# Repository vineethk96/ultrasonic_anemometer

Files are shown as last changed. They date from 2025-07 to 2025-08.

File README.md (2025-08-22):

# Ultrasonic Anemometer Project

A complete 2D ultrasonic wind speed and direction measurement system with wireless data transmission and statistical analysis capabilities.

## Project Overview

This project implements a sonic anemometer that measures wind speed and direction using ultrasonic transducers. The system consists of three main components:

1. **Anemometer Device** - Arduino-based sensor that calculates wind measurements.
2. **WiFi Module** - ESP32-based wireless transmission system.
3. **Data Collection & Analysis** - Python scripts for data gathering and statistical analysis.
4. **CAD** - CAD Files for initial designs for 3D anemometer, and completed 2D anemometer. Along with the designs and laser-cut drawings for the model.

## System Architecture

```
[Ultrasonic Signal Board] → [Arduino Uno] → [Serial] → [ESP32] → [MQTT] → [Python Data Collector]
                                    ↓
                            [7-Segment Display]
```

## Hardware Requirements

### Anemometer Components
- Arduino Uno
- 3x Ultrasonic RX transducers (North, East, West)
- 1x Ultrasonic TX transducer
- 4-digit 7-segment display (common cathode)
- Various electronic components
- PCB

### WiFi Module Components
- ESP32 development board (ESP32-S3-DevKitC-1)
- Serial connection to anemometer Arduino

### Additional Components
- 9V Wall Wart with power pigtails
- Enclosure/mounting hardware (see CAD folder)

## Software Requirements

- **PlatformIO** (recommended) or Arduino IDE
- **Python 3.7+** with packages:
  - `paho-mqtt`
  - `pandas`
  - `numpy`
  - `statsmodels`
  - `scipy`

## Quick Start Guide

### 1. Hardware Setup
**_NOTE:_**  Please see [Instructable](https://www.instructables.com/Sonic-Anemometer/) for help in assembly. 
1. Build the anemometer circuit following the pin configurations in `anemometer/src/main.cpp`
2. Connect ultrasonic transducers
3. Wire the 7-segment display to digital pins 2-13
4. Connect Arduino to ESP32 via serial (9600 baud)

### 2. Software Installation
1. Install PlatformIO in VS Code
2. Clone this repository
3. Install Python dependencies:
   ```bash
   pip install paho-mqtt pandas numpy statsmodels scipy
   ```

### 3. Configuration
1. Create `arduino_secrets.h` in `WiFi_Module/include/` with your credentials:
   ```cpp
   #define SECRET_SSID "your_wifi_ssid"
   #define SECRET_PASS "your_wifi_password"
   #define SECRET_MQTTUSER "your_mqtt_username"
   #define SECRET_MQTTPASS "your_mqtt_password"
   ```

### 4. Upload Code
1. Upload `anemometer` code to Arduino Micro/Uno
2. Upload `WiFi_Module` code to ESP32

### 5. Data Collection
1. Run the MQTT collector:
   ```bash
   cd data_collector
   python mqtt_collector.py
   ```
2. Follow prompts to collect 200 readings
3. Use `merger.py` to combine multiple CSV files
4. Run `analysis.py` for statistical analysis

## Calibration

The anemometer requires calibration in three conditions:
1. **Still air** (calm conditions)
2. **Known north wind** (9 m/s reference)
3. **Known east wind** (9 m/s reference)

Update the calibration values in `anemometer/src/main.cpp`:
```cpp
const Wind_t calm =   {547, 581}; // Still air readings
const Wind_t north =  {850, 226}; // North wind readings  
const Wind_t east =   {720, 712}; // East wind readings
```

## Data Format

The system outputs JSON-formatted wind data:
```json
{"speed": 5.50, "direction": 126}
```

Where:
- `speed`: Wind speed in m/s
- `direction`: Wind direction in degrees (0-360°, meteorological convention)

## Folder Structure

```
├── anemometer/          # Arduino code for wind calculations
│   ├── src/main.cpp     # Main anemometer logic
│   ├── lib/sevSeg/      # 7-segment display library
│   └── platformio.ini   # Build configuration
├── WiFi_Module/         # ESP32 WiFi transmission code
│   ├── src/main.cpp     # MQTT publishing logic
│   └── platformio.ini   # ESP32 build configuration
├── data_collector/      # Python data collection tools
│   ├── mqtt_collector.py   # MQTT data collection script
│   ├── merger.py           # CSV file merger utility
│   └── analysis.py         # Statistical analysis tools
└── CAD/                 # 3D models and mechanical designs
    ├── Device             # STL files to print 2D Anemometer
    └── Exhibit            # Mix of STL and DXF files to make scaled
```

## Detailed Documentation

Each folder contains its own README with specific setup instructions:
- [Anemometer README](anemometer/README.md) - Arduino setup and calibration
- [WiFi Module README](WiFi_Module/README.md) - ESP32 configuration and MQTT setup
- [Data Collector README](data_collector/README.md) - Python tools and analysis

## Troubleshooting

### Common Issues

**No MQTT data received:**
- Check WiFi credentials in `arduino_secrets.h`
- Verify MQTT broker connectivity
- Ensure serial connection between Arduino and ESP32

**Incorrect wind measurements:**
- Recalibrate sensors in known conditions
- Check transducer positioning (East/West alignment)
- Verify analog pin connections

**7-segment display not working:**
- Check pin connections match code configuration
- Verify common cathode display type
- Test with simple digit display first

## Contributing

1. Fork the repository
2. Create a feature branch
3. Make your changes
4. Test with hardware setup
5. Submit a pull request

## License

This project is open source. See individual files for specific licensing information.

## Acknowledgments

This project uses:
- PlatformIO for embedded development
- PubSubClient library for MQTT communication
- ArduinoJson for data formatting
- Python scientific stack for data analysis
- Claude Sonnet 4 was used in the following capacities on the Python scripts:
   - Merging CSV files
   - Cleaning up the output of scripts
   - Conducting ANOVA tests

---

For detailed component-specific instructions, see the README files in each subfolder.

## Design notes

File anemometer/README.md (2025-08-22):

# Anemometer - Wind Measurement Module

This folder contains the Arduino code for the ultrasonic anemometer that calculates 2D wind speed and direction measurements.

## Overview

The anemometer uses three ultrasonic transducers positioned North, East, and West to measure wind speed and direction through phase-shift calculations. Wind data is displayed on a 7-segment display and transmitted via serial to the WiFi module.

## Hardware Requirements

- **Arduino Uno**
- **3x RX Ultrasonic Transducers** (positioned North, East, West)
- **1x TX Ultrasonic Transducer** 
- **4-digit 7-segment display** (common cathode)
- **Resistors** (220Ω recommended for segment limiting)
- **Various other electrical components**

## Pin Configuration

### Analog Inputs
- `A0` - West ultrasonic transducer
- `A1` - East ultrasonic transducer
- North RX Transducer is phase-locked to TX

### 7-Segment Display (Common Cathode)
#### Digit Control Pins:
- `Pin 3` - Digit 1 (leftmost)
- `Pin 2` - Digit 2  
- `Pin 13` - Digit 3
- `Pin 12` - Digit 4 (rightmost)

#### Segment Control Pins (a, b, c, d, e, f, g, dp):
- `Pin 4` - Segment A
- `Pin 5` - Segment B
- `Pin 6` - Segment C
- `Pin 7` - Segment D
- `Pin 8` - Segment E
- `Pin 9` - Segment F
- `Pin 10` - Segment G
- `Pin 11` - Decimal Point

## Software Setup

### 1. Install PlatformIO
Install the PlatformIO extension in VS Code or use PlatformIO Core.

### 2. Open Project
Open the `anemometer` folder in PlatformIO.

### 3. Select Environment
The `platformio.ini` file defines two environments:
- `uno` - for Arduino Uno

Select the appropriate environment in PlatformIO.

### 4. Upload Code
```bash
pio run --target upload --environment uno
```

## Calibration Process

The anemometer requires calibration in three wind conditions. Update these values in `src/main.cpp`:

```cpp
// Calibration values for the sensors in still air
const Wind_t calm =   {547, 581}; // W, E sensor readings in calm air
const Wind_t north =  {850, 226}; // W, E sensor readings in 10 m/s north wind  
const Wind_t east =   {720, 712}; // W, E sensor readings in 10 m/s east wind
```

### Calibration Steps:
1. **Calm Air Calibration:**
   - Place anemometer in still air conditions
   - Record average readings from both sensors
   - Update `calm` values

2. **North Wind Calibration:**
   - Generate known 9 m/s wind from north direction
   - Record sensor readings
   - Update `north` values

3. **East Wind Calibration:**
   - Generate known 9 m/s wind from east direction
   - Record sensor readings  
   - Update `east` values

## Code Structure

### Main Components

#### `main.cpp`
- **Wind Calculation Algorithm:** Implements 2D vector wind speed/direction calculation
- **Moving Average Filter:** 50-sample rolling average for noise reduction
- **Sensor Reading:** Alternates between East/West sensors every 100μs
- **Display Control:** Updates 7-segment display every second
- **Serial Output:** Sends JSON wind data via serial

#### Custom Library: `sevSeg`
Located in `lib/sevSeg/`, this library handles the 4-digit 7-segment display:

- **`sevSeg.hpp`** - Class definition and interface
- **`sevSeg.cpp`** - Implementation with digit encoding and multiplexing

### Key Parameters

```cpp
#define ADC_DELAY_US 100          // Delay between sensor readings (μs)
#define MOVING_AVERAGE_SIZE 50    // Rolling average window size
#define DISPLAY_UPDATE_RATE 1000  // Display refresh rate (ms)
```

### Data Structures

```cpp
typedef struct{
  float windSpeed;     // Wind speed in m/s
  int windDirection;   // Wind direction in degrees (0-360°)
} WindData_t;

typedef struct{
  int W;  // West sensor reading
  int E;  // East sensor reading  
} Wind_t;
```

## Algorithm Details

### Wind Calculation Process
1. **Sensor Reading:** Alternates between East/West transducers
2. **Moving Average:** Maintains 50-sample rolling average for each sensor
3. **Vector Calculation:** 
   - Calculates North and East wind components using calibration data
   - Uses linear interpolation between calm and reference wind conditions
4. **Wind Speed:** `sqrt(north² + east²) / 2`
5. **Wind Direction:** `atan2(north, east)` converted to 0-360° meteorological convention

### Output Format
```json
{"speed":5.50,"direction":126}
```

Serial output at 9600 baud for transmission to WiFi module.

## Display Features

- **Wind Speed Display:** Shows current wind speed in m/s (integer value)
- **Multiplexed Display:** Efficient 4-digit display with 1ms refresh rate
- **Leading Zero Suppression:** Hides unnecessary leading zeros
- **Range:** Displays 0-9999 (wind speeds over 999 m/s show as 9999)

## Troubleshooting

### No Display Output
- Check 7-segment display wiring
- Verify common cathode display type
- Test individual segments with simple code

### Incorrect Wind Readings
- Recalibrate sensors with known wind conditions
- Check transducer alignment (ensure East-West positioning)
- Verify analog input connections

### Erratic Readings
- Increase moving average window size
- Check for electrical interference
- Ensure stable power supply

### Serial Communication Issues
- Verify 9600 baud rate setting
- Check serial connection to ESP32
- Monitor serial output with Arduino IDE Serial Monitor

## Monitoring and Testing

### Serial Monitor Output
Connect to the Arduino's serial port at 9600 baud to see:
- JSON wind data: `{"speed":X.XX,"direction":XXX}`
- Calibration verification data
- Error messages and diagnostics

### Testing Procedure
1. Upload code to Arduino
2. Open Serial Monitor (9600 baud)
3. Verify JSON output format
4. Test display with known wind conditions
5. Validate readings against reference measurements

## Performance Specifications

- **Update Rate:** Wind calculations every 200μs (5 kHz)
- **Display Update:** 1 Hz (1 second intervals)
- **Serial Output:** Continuous JSON stream
- **Accuracy:** Depends on calibration quality and sensor positioning
- **Range:** 0-999 m/s (display limitation)

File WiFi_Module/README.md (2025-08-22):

# WiFi Module - Wireless Data Transmission

This folder contains the ESP32 code for wireless transmission of wind data via MQTT protocol.

## Overview

The WiFi module receives JSON wind data from the anemometer via serial communication and publishes it to an MQTT broker for remote data collection and analysis.

## Hardware Requirements

- **ESP32 Development Board** (one of the following):
  - ESP32-S3-DevKitC-1 (recommended)
  - ESP32-DevKit-V4
- **Serial connection** to Arduino anemometer (3.3V/5V compatible)
- **USB cable** for programming and power
- **WiFi network** access

## Pin Connections

### Serial Communication with Anemometer
- **RX Pin** - Connect to Arduino TX (Serial output from anemometer)
- **GND** - Common ground between ESP32 and Arduino
- **Power** - Ensure compatible voltage levels (3.3V/5V)

**Note:** ESP32 serial pins are typically GPIO1 (TX) and GPIO3 (RX) for Serial0, but this varies by board model.

## Software Setup

### 1. Install PlatformIO
Install PlatformIO extension in VS Code or use PlatformIO Core CLI.

### 2. Create Secrets File
Create `include/arduino_secrets.h` with your network credentials:

```cpp
#ifndef ARDUINO_SECRETS_H
#define ARDUINO_SECRETS_H

// WiFi Credentials
#define SECRET_SSID "your_wifi_network_name"
#define SECRET_PASS "your_wifi_password"

// MQTT Credentials  
#define SECRET_MQTTUSER "your_mqtt_username"
#define SECRET_MQTTPASS "your_mqtt_password"

#endif
```

**Security Note:** This file is in `.gitignore` to prevent credential exposure.

### 3. Select Board Environment
The `platformio.ini` defines two environments:

```ini
[env:esp32-s3-devkitc-1]    # For ESP32-S3 boards
[env:esp32-devkitC_v4]      # For ESP32 DevKit V4 boards
```

### 4. Upload Code
```bash
# For ESP32-S3
pio run --target upload --environment esp32-s3-devkitc-1

# For ESP32 DevKit V4  
pio run --target upload --environment esp32-devkitC_v4
```

## MQTT Configuration

### Broker Settings
The code is pre-configured for the CETools MQTT broker:
- **Host:** `mqtt.cetools.org`
- **Port:** `1884`
- **Topic:** `student/ultrasonic_anemometer`

### Topic Structure
Data is published to: `student/ultrasonic_anemometer`

### Authentication
Uses username/password authentication as defined in `arduino_secrets.h`.

## Code Structure

### Main Components

#### `main.cpp`
- **WiFi Management:** Automatic connection and reconnection
- **MQTT Client:** Handles broker connection and publishing
- **Serial Communication:** Receives data from anemometer at 9600 baud
- **Data Forwarding:** Publishes received JSON data to MQTT

### Key Functions

#### `startWifi()`
- Initializes WiFi connection
- Displays connection status and IP address
- Blocks until connected

#### `checkWifi()`
- Monitors WiFi connection status
- Automatically reconnects if disconnected
- Called every 10 seconds (INTERVAL)

#### `checkMQTT()`
- Maintains MQTT broker connection
- Handles authentication and reconnection
- Called continuously in main loop

#### `sendMQTT(char *msg)`
- Publishes wind data to MQTT topic
- Provides confirmation feedback via Serial
- Handles publish failures gracefully

### Connection Management
The system implements robust connection handling:
- **WiFi Auto-Reconnect:** Checks connection every 10 seconds
- **MQTT Persistence:** Maintains broker connection continuously
- **Error Recovery:** Automatic retry with delays
- **Status Reporting:** Serial output for debugging

## Data Flow

```
[Arduino] --Serial 9600--> [ESP32] --WiFi--> [MQTT Broker] ---> [Data Collector]
```

1. **Serial Input:** ESP32 receives JSON strings from Arduino
2. **Format Validation:** Accepts complete lines ending with `\n`
3. **MQTT Publishing:** Forwards data to configured topic
4. **Confirmation:** Serial feedback confirms successful transmission

## Expected Data Format

The system expects JSON wind data from the anemometer:
```json
{"speed":5.50,"direction":126}
```

Invalid formats are discarded with error messages.

## Monitoring and Debugging

### Serial Monitor Output
Connect to ESP32 at 9600 baud to monitor:
```
ESP32 MQTT
Connecting to WiFi..
Connected: 192.168.1.100
Attempting MQTT connection...connected
SENDING MSG...
Topic: student/ultrasonic_anemometer  
Message: {"speed":5.50,"direction":126}
Message published
```

### Connection Status Messages
- **WiFi:** IP address displayed on successful connection
- **MQTT:** Connection confirmation with client ID
- **Publish:** Topic and message content logged
- **Errors:** Failed connections and retry attempts

## Troubleshooting

### WiFi Connection Issues
1. **Check Credentials:**
   - Verify SSID and password in `arduino_secrets.h`
   - Ensure network is 2.4GHz (ESP32 limitation)

2. **Network Compatibility:**
   - Test with mobile hotspot
   - Check for enterprise/captive portal networks

3. **Signal Strength:**
   - Move closer to WiFi router
   - Check antenna connection on ESP32

### MQTT Connection Problems
1. **Broker Access:**
   - Verify `mqtt.cetools.org` is accessible
   - Test with MQTT client tools (mosquitto_pub/sub)

2. **Credentials:**
   - Confirm MQTT username/password
   - Check account permissions

3. **Firewall Issues:**
   - Ensure port 1884 is not blocked
   - Test from different network

### Serial Communication Issues
1. **Arduino Connection:**
   - Check serial wiring between Arduino and ESP32
   - Verify ground connection
   - Confirm voltage compatibility (3.3V/5V)

2. **Baud Rate:**
   - Both devices must use 9600 baud
   - Check Arduino serial output first

3. **Data Format:**
   - ESP32 expects complete lines (ending with `\n`)
   - Arduino should use `Serial.println()`

### No Data Publishing
1. **Check Serial Input:**
   - Monitor ESP32 serial for incoming messages
   - Verify Arduino is sending data

2. **MQTT Connection:**
   - Ensure MQTT client shows "connected" status
   - Test topic subscription with external client

3. **Message Format:**
   - ESP32 forwards received messages directly
   - Any string from Arduino will be published

## Performance Specifications

- **Serial Baud Rate:** 9600 bps
- **WiFi Standard:** 802.11 b/g/n (2.4GHz)
- **MQTT QoS:** 0 (fire-and-forget)
- **Reconnection Interval:** 10 seconds (WiFi), 5 seconds (MQTT)
- **Message Rate:** Unlimited (forwards all received data)

## Power Considerations

- **USB Power:** Suitable for development and testing
- **External Power:** 3.3V-5V DC input for permanent installation
- **Power Consumption:** ~160mA active, ~10μA deep sleep (if implemented)

## Libraries Used

- **WiFi:** ESP32 built-in WiFi library
- **PubSubClient:** MQTT client implementation (v2.8+)
- **ArduinoJson:** JSON formatting library (v7.4.2+)

These dependencies are automatically managed by PlatformIO.

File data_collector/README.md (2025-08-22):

# Data Collector - Python Analysis Tools

This folder contains Python scripts for collecting, processing, and analyzing wind data from the ultrasonic anemometer system.

## Overview

The data collector suite provides three main tools:
1. **MQTT Collector** - Real-time data collection from MQTT broker
2. **CSV Merger** - Combines multiple data files for analysis
3. **Statistical Analysis** - Comprehensive ANOVA and effect size analysis

## Requirements

### Python Version
- Python 3.7 or higher

### Required Packages
Create a Virtual Environment:
```bash
python -m venv analysis_env
```

Start Virtual Environment:
```bash
analysis_env\Scripts\activate
```

Install the required packages using pip:

```bash
pip install paho-mqtt pandas numpy statsmodels scipy
```

Or install from requirements file:
```bash
pip install -r requirements.txt
```

**_NOTE:_** Remember to deactivate Virtual Environment after use
```bash
deactivate
```

#### Package Details:
- `paho-mqtt>=1.6.1` - MQTT client for data collection
- `pandas>=1.3.0` - Data manipulation and analysis
- `numpy>=1.21.0` - Numerical computations
- `statsmodels>=0.12.0` - Statistical modeling and ANOVA
- `scipy>=1.7.0` - Scientific computing and statistics

## Tools Overview

### 1. MQTT Collector (`mqtt_collector.py`)

Connects to MQTT broker and collects 200 wind readings in real-time.

#### Usage:
```bash
python mqtt_collector.py
```

#### Interactive Setup:
1. **CSV Filename:** Enter desired output filename (`.csv` added automatically)
2. **MQTT Topic:** Enter the topic to subscribe to (e.g., `student/ultrasonic_anemometer`)
3. **Confirmation:** Review settings and confirm collection

#### Features:
- **Real-time Collection:** Streams live data from MQTT broker
- **Format Validation:** Parses JSON format `{"speed":X.XX,"direction":XXX}`
- **Progress Tracking:** Shows collection progress (X/200 readings)
- **Automatic Statistics:** Calculates mean, min, max, std deviation
- **Error Handling:** Graceful handling of connection issues
- **Interrupt Support:** Ctrl+C saves partial data

#### Output Format:
CSV file with columns:
- `timestamp` - ISO format timestamp
- `topic` - MQTT topic name
- `wind_speed` - Wind speed in m/s
- `wind_direction` - Wind direction in degrees

#### Example Output:
```csv
timestamp,topic,wind_speed,wind_direction
2024-01-15T14:30:15.123456,student/ultrasonic_anemometer,5.50,126
2024-01-15T14:30:16.234567,student/ultrasonic_anemometer,5.75,128
```

### 2. CSV Merger (`merger.py`)

Combines multiple CSV files into a single summary file for batch analysis.

#### Usage:
```bash
python merger.py
```

#### Interactive Process:
1. **Directory Path:** Enter path containing CSV files
2. **File Discovery:** Automatically finds all `.csv` files
3. **Processing:** Extracts wind_speed data from each file
4. **Output:** Creates `wind_speed_summary.csv`

#### Features:
- **Batch Processing:** Handles multiple CSV files automatically
- **Column Validation:** Verifies required columns exist
- **Filename Preservation:** Creates unique column names from filenames
- **Error Handling:** Skips invalid files with warnings
- **Data Preview:** Shows first few rows of combined data

#### Output Structure:
```csv
index,file1_wind_speed,file2_wind_speed,file3_wind_speed
1,5.50,6.20,4.80
2,5.75,6.45,4.95
```

### 3. Statistical Analysis (`analysis.py`)

Performs comprehensive statistical analysis on wind speed data collected under different experimental conditions.

#### Usage:
```bash
python analysis.py
```

#### Required Data Structure:
The script expects CSV files organized by experimental conditions in a `readings/` directory:

```
readings/
├── aboveTreeLevel/
│   ├── open.csv
│   ├── half_building.csv
│   ├── closed_park.csv
│   └── ...
├── treeLevel/
│   └── ...
└── groundLevel/
    └── ...
```

#### Experimental Factors:
- **Height:** `aboveTreeLevel`, `treeLevel`, `groundLevel`
- **Width:** `open`, `half`, `closed`  
- **Obstacles:** `none`, `building`, `park`

#### Statistical Methods:

##### 1. Two-Way ANOVA (by height level)
- **Factors:** Width × Obstacles
- **Response:** Wind speed
- **Type:** Type II ANOVA (balanced designs)

##### 2. Three-Way ANOVA (all data)
- **Factors:** Height × Width × Obstacles
- **Includes:** All main effects and interactions

##### 3. Effect Size Analysis
- **Omega Squared (ω²):** Less biased than eta squared
- **Interpretation:** 
  - < 0.01: negligible
  - 0.01-0.06: small
  - 0.06-0.14: medium  
  - ≥ 0.14: large

##### 4. Specific Contrasts
- **Obstacle Effects:** Building vs None, Park vs None
- **Confidence Intervals:** 95% CI for effect differences
- **Interaction Analysis:** Effects by height level

#### Output Features:
- **Data Quality Checks:** Sample sizes, missing data, descriptive stats
- **ANOVA Tables:** F-statistics, p-values, degrees of freedom
- **Effect Sizes:** Omega squared with magnitude interpretation
- **Contrast Analysis:** Specific comparisons of interest
- **Summary Statistics:** Overall dataset characteristics

#### Example Output:
```
TWO-WAY ANOVA ANALYSES BY HEIGHT
================================

Two-Way ANOVA for aboveTreeLevel
================================
                    sum_sq    df         F    PR(>F)
C(width)            45.23     2    8.756   0.0003
C(obstacles)        12.34     2    2.389   0.0956
C(width):C(obstacles) 3.45   4    0.334   0.8551
Residual           234.56    91

Omega Squared (O_sq) Effect Sizes:
-----------------------------------
C(width)                      : O_sq = 0.1234 (medium)
C(obstacles)                  : O_sq = 0.0234 (small)
C(width):C(obstacles)         : O_sq = 0.0000 (negligible)
```

## Workflow Example

### Complete Data Collection and Analysis Workflow:

1. **Collect Data:**
   ```bash
   python mqtt_collector.py
   # Collect data for each experimental condition
   # Example: open_none_height1.csv, open_building_height1.csv, etc.
   ```

2. **Organize Data:**
   ```
   mkdir -p readings/aboveTreeLevel readings/treeLevel readings/groundLevel
   # Move CSV files to appropriate directories
   # Rename files to match expected format (width_obstacle.csv)
   ```

3. **Optional - Merge Multiple Files:**
   ```bash
   python merger.py
   # If you have multiple files per condition to combine
   ```

4. **Run Analysis:**
   ```bash
   python analysis.py
   # Performs complete statistical analysis
   ```

## Data Quality Requirements

### File Naming Convention:
- Format: `{width}_{obstacle}.csv` (e.g., `open_building.csv`)
- Width options: `open`, `half`, `closed`
- Obstacle options: `none`, `building`, `park`
- Special case: Files with just width name (e.g., `open.csv`) assume `obstacle = none`

### CSV Structure:
Required columns in each CSV file:
- `wind_speed` - Numerical wind speed values
- Other columns (timestamp, topic, wind_direction) are preserved but not required for analysis

### Sample Size Considerations:
- **Minimum:** 30 readings per condition for reliable statistics
- **Recommended:** 200 readings per condition for robust analysis
- **Balance:** Equal sample sizes across conditions improve ANOVA reliability

## Troubleshooting

### MQTT Collection Issues:

**Connection Failed:**
```
Failed to connect to MQTT broker. Return code: X
```
- Check internet connection
- Verify MQTT broker address (`mqtt.cetools.org`)
- Test with MQTT client tools

**No Data Received:**
```
Skipped invalid format: some_message
```
- Check ESP32 is publishing to correct topic
- Verify data format: `{"speed":X.XX,"direction":XXX}`
- Monitor Arduino serial output

**Incomplete Collection:**
- Use Ctrl+C to save partial data
- Check WiFi stability during collection
- Restart collection if needed

### Analysis Issues:

**File Not Found:**
```
FileNotFoundError: readings/ directory not found
```
- Create `readings/` directory structure
- Move CSV files to appropriate subdirectories
- Check file naming convention

**Missing Columns:**
```
KeyError: 'wind_speed' column not found
```
- Verify CSV files have `wind_speed` column
- Check column names match exactly
- Review CSV file structure

**Insufficient Data:**
```
Warning: Small sample size in condition X
```
- Collect more data for affected conditions
- Consider combining similar conditions
- Check for missing experimental conditions

### CSV Merger Issues:

**No CSV Files Found:**
```
No CSV files found in directory 'path'
```
- Check directory path is correct
- Ensure files have `.csv` extension
- Verify file permissions

**Column Validation Failed:**
```
Warning: file.csv missing required columns. Skipping.
```
- Check CSV file structure
- Ensure required columns exist: `timestamp`, `topic`, `wind_speed`, `wind_direction`
- Review file formatting

## Performance Notes

- **MQTT Collection:** ~1-5 readings/second depending on transmission rate
- **CSV Merger:** Handles files up to 1M+ rows efficiently
- **Analysis:** Processing time scales with dataset size, typically <30 seconds for normal datasets

## Advanced Configuration

### MQTT Broker Settings:
Modify `mqtt_collector.py` to use different brokers:
```python
collector = MQTTDataCollector("your.mqtt.broker.com", port=1883)
```

### Analysis Customization:
Modify `analysis.py` for different experimental designs:
- Change factor names

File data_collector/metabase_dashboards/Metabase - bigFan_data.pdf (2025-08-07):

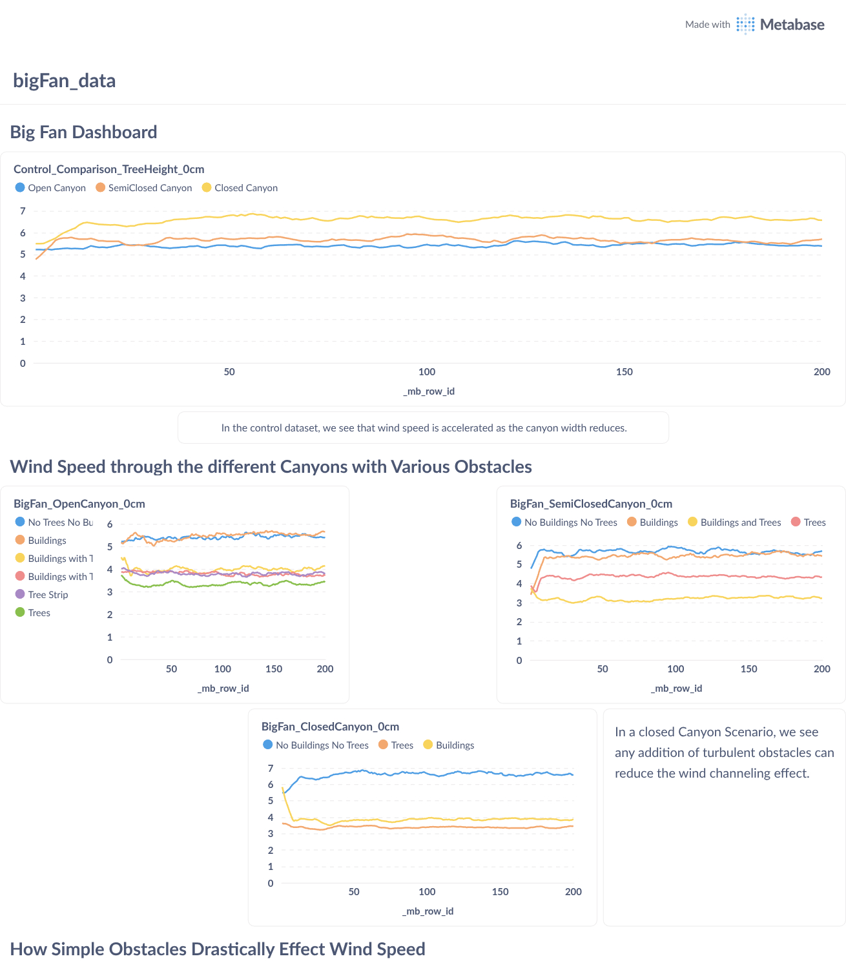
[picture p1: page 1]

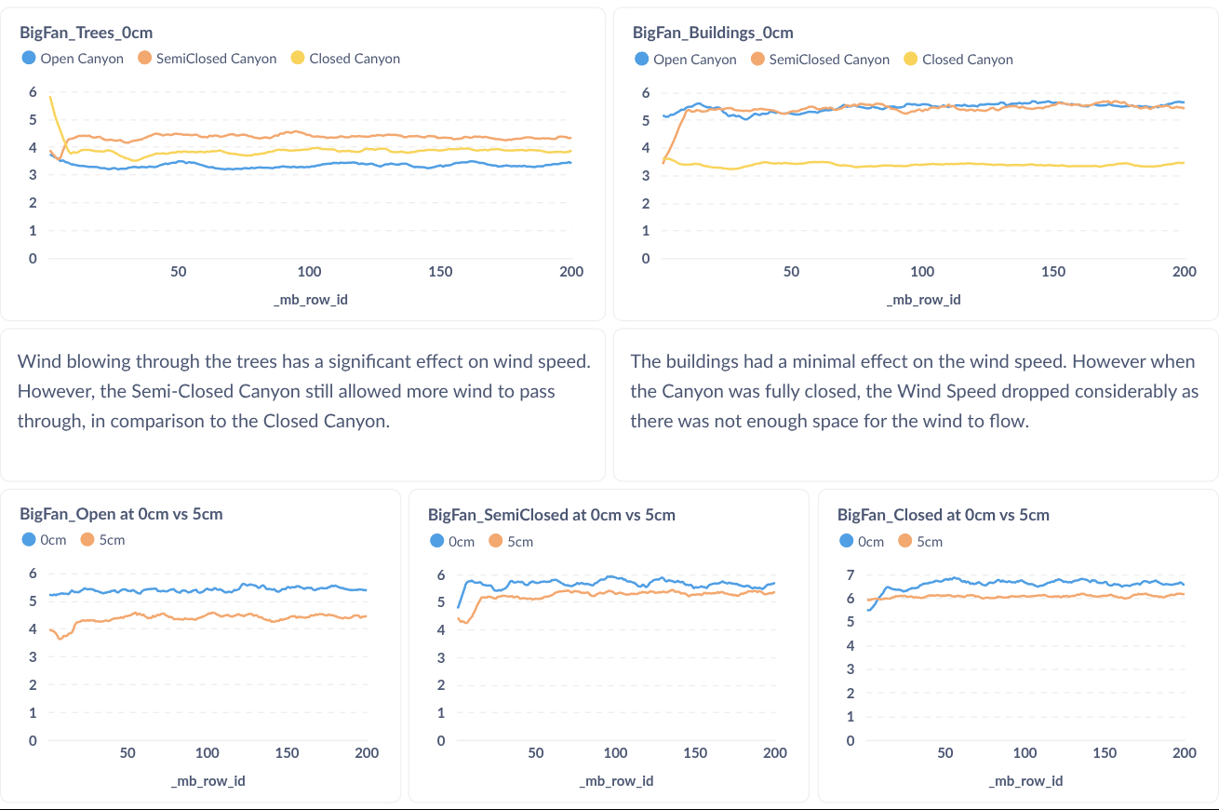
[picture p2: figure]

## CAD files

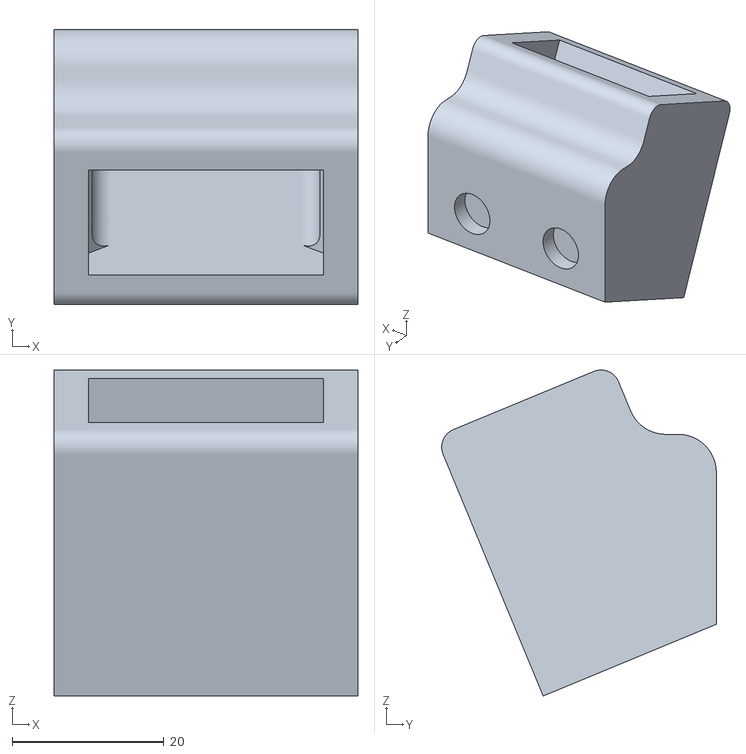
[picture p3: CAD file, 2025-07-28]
CAD/Device/screenHolder.stl
40.0 x 36.2 x 42.9

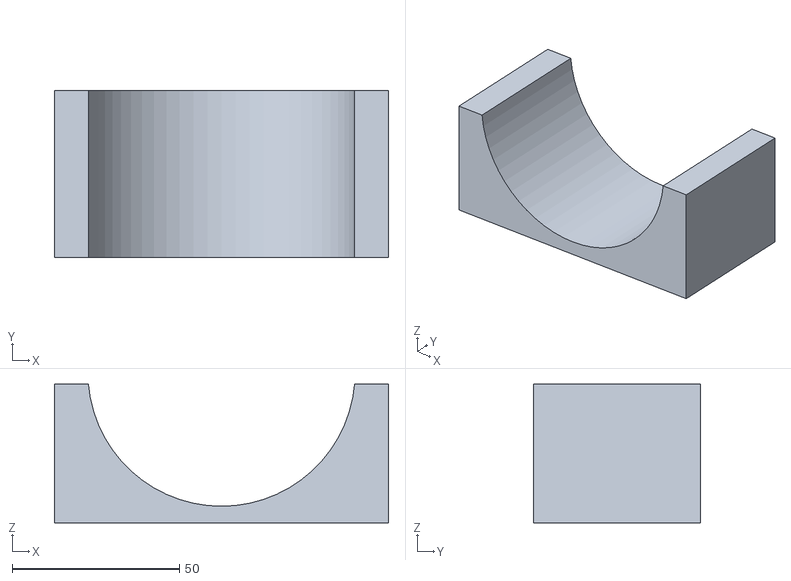
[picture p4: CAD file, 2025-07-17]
CAD/Exhibit/skateRamp - Part 1.stl
100.0 x 50.0 x 41.6

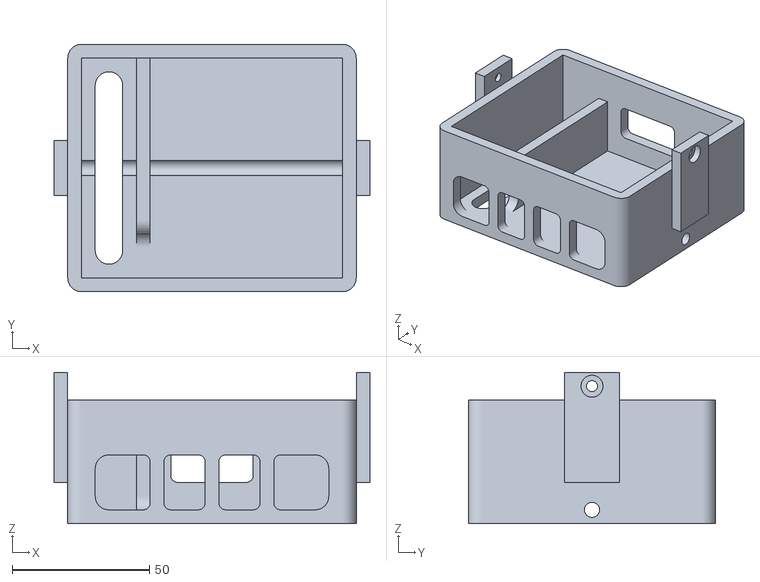
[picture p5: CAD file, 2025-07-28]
CAD/Device/arduinoBox.stl
115.0 x 90.0 x 55.0

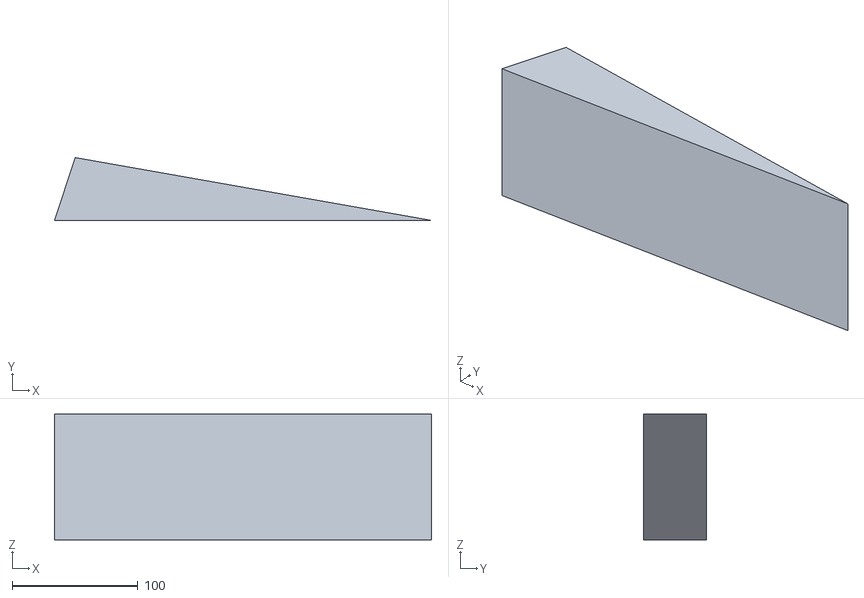
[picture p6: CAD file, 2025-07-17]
CAD/Exhibit/ramps - Part 1.stl
300.0 x 50.0 x 100.0

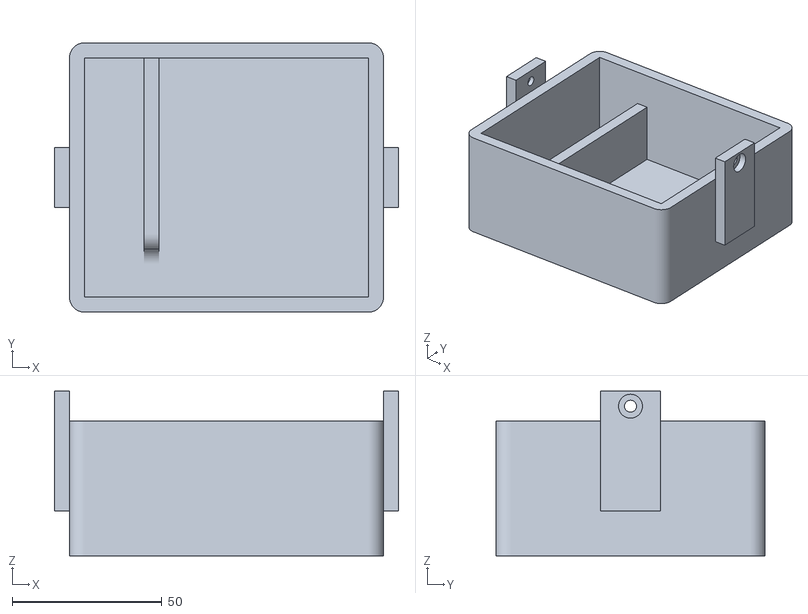
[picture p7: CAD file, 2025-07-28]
CAD/Device/batteryBox.stl
115.0 x 90.0 x 55.0

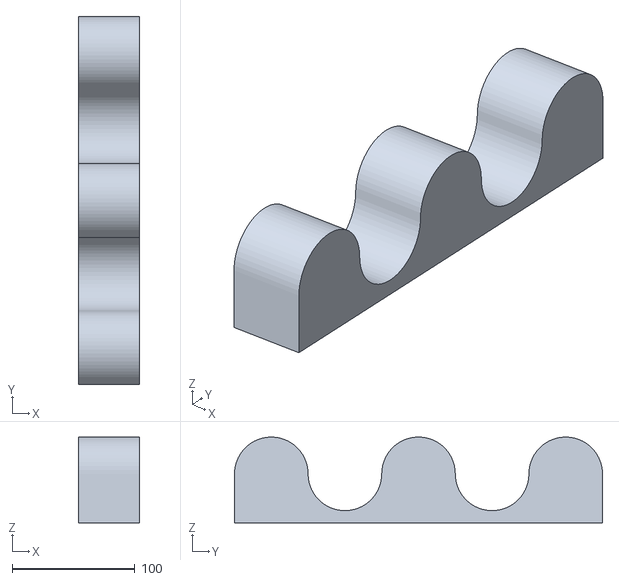
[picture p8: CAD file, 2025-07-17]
CAD/Exhibit/rollingHills - Part 1.stl
50.0 x 300.0 x 70.0

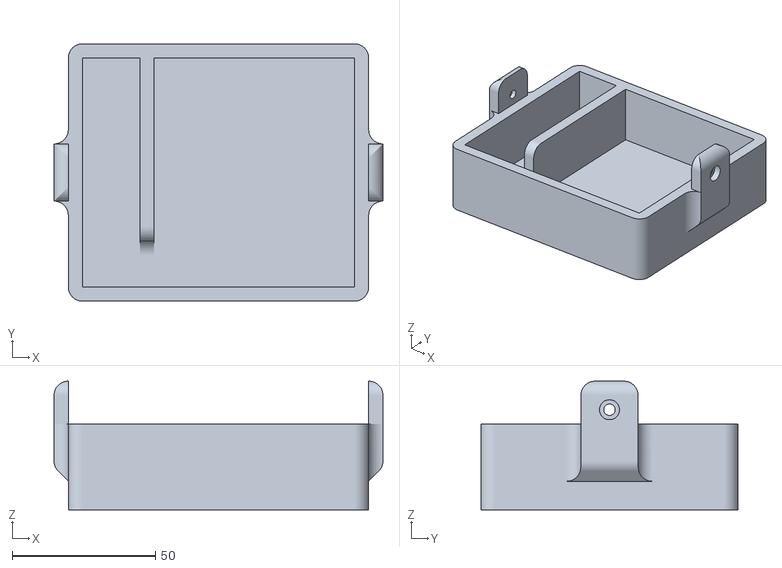
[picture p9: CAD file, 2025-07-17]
CAD/Device/circuitBox - Part 1.stl
115.0 x 90.0 x 45.0

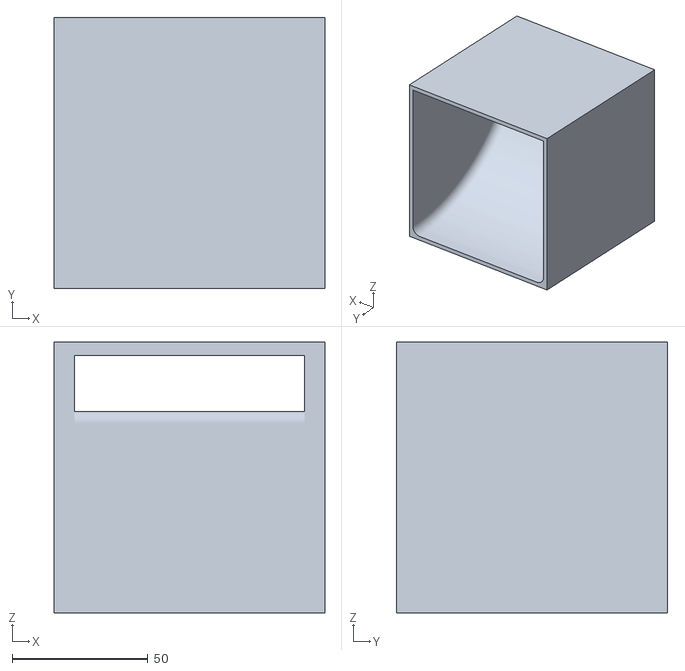
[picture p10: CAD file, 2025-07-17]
CAD/Exhibit/accelerator box - Part 1.stl
100.0 x 100.0 x 100.0

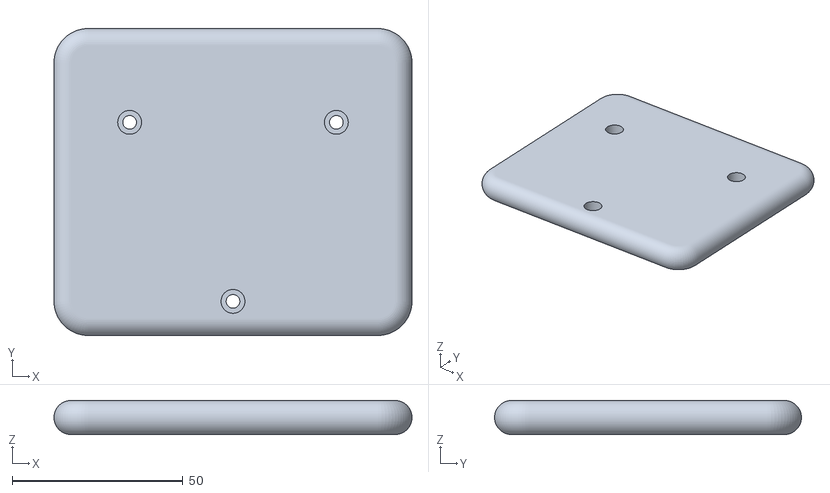
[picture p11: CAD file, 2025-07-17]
CAD/Device/reflector_plate- Part 1.stl
105.0 x 90.0 x 10.0

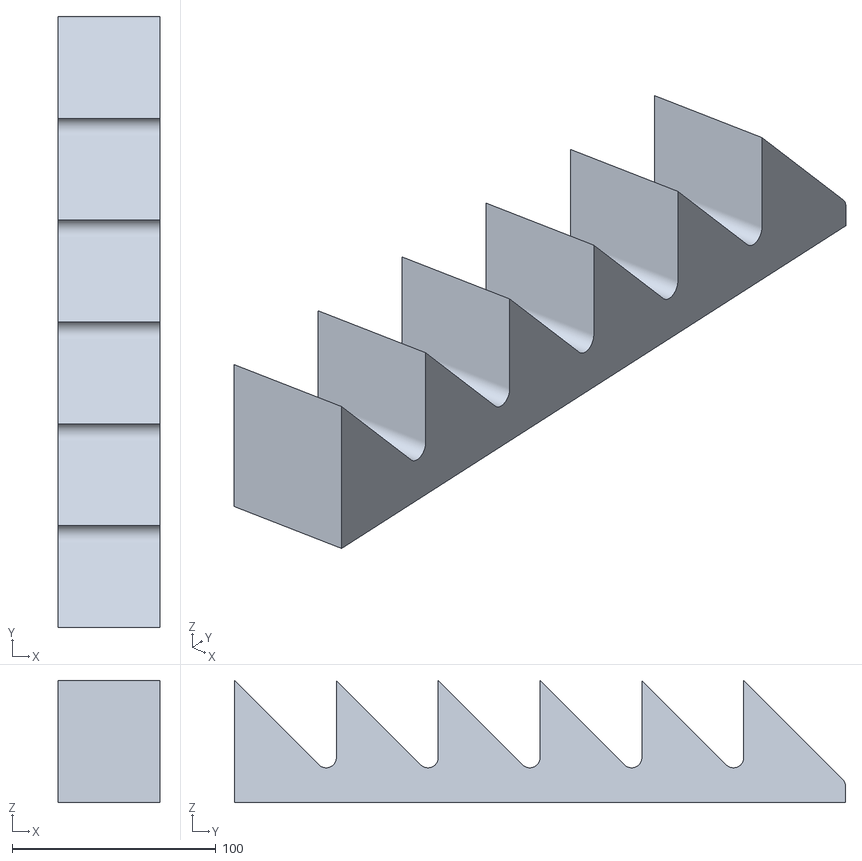
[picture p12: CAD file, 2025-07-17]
CAD/Exhibit/fins - Part 1.stl
50.0 x 300.0 x 60.0

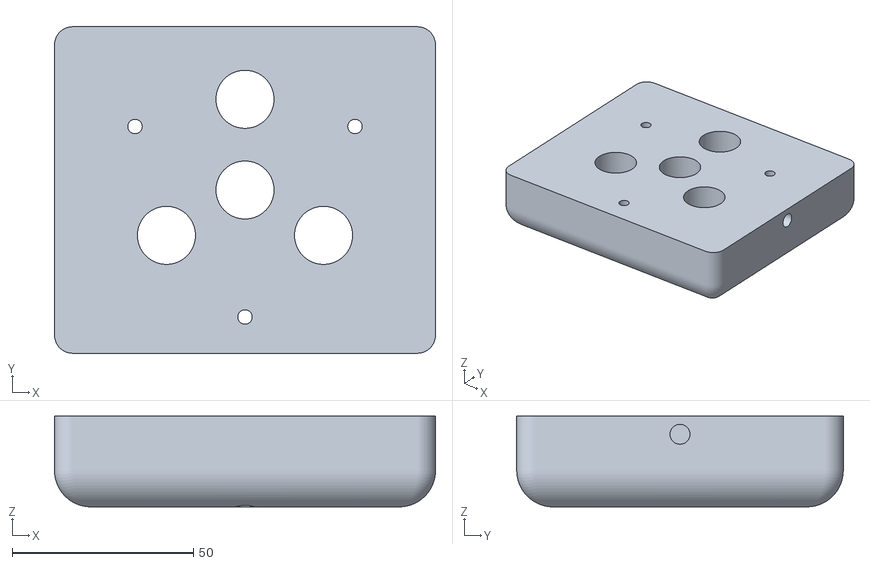
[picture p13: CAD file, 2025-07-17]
CAD/Device/rectangular_Tplate - Part 1.stl
105.0 x 90.0 x 25.0

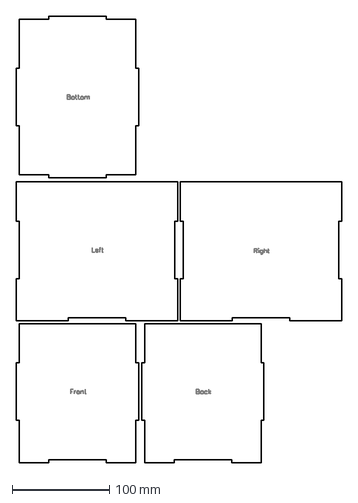
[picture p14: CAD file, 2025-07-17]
CAD/Exhibit/fanBox.dxf
335.0 x 459.5 mm

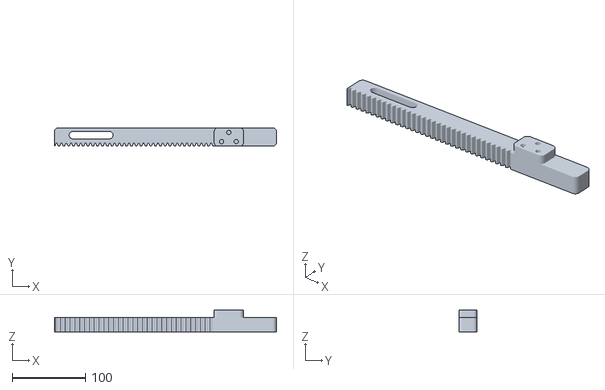
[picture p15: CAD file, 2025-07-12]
CAD/Exhibit/Upper Rack_v2.stl
303.0 x 25.0 x 30.0

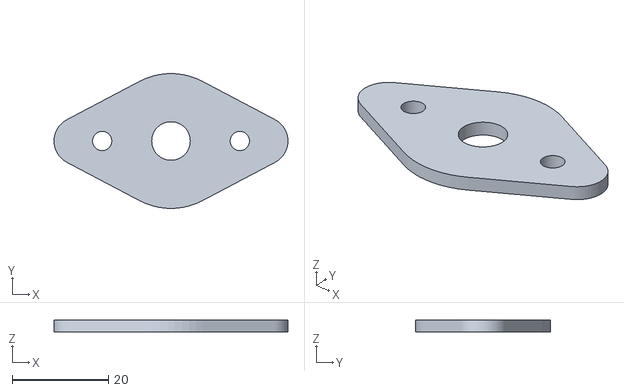
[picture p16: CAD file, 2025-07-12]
CAD/Exhibit/pinionGearMount.stl
48.6 x 28.0 x 2.40

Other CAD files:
CAD/Exhibit/baseBox.dxf
CAD/Exhibit/Spur Gear 36 Teeth - Spur Gear.stl
CAD/Exhibit/building.dxf
CAD/Exhibit/Upper Rack.stl
CAD/Exhibit/fins - Part 1.dxf
CAD/Exhibit/ramps - Part 1.dxf
CAD/Exhibit/rollingHills - Part 1.dxf
CAD/Exhibit/skateRamp - Part 1.dxf

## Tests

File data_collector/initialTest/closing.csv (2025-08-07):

timestamp | topic | wind_speed | wind_direction
2025-08-05T15:08:18.526827 | student/ultrasonic_anemometer | 5.45 | 126.0
2025-08-05T15:08:19.529580 | student/ultrasonic_anemometer | 5.4 | 126.0
2025-08-05T15:08:20.600967 | student/ultrasonic_anemometer | 5.41 | 126.0
2025-08-05T15:08:21.536490 | student/ultrasonic_anemometer | 5.42 | 127.0
2025-08-05T15:08:22.579929 | student/ultrasonic_anemometer | 5.4 | 126.0
2025-08-05T15:08:23.541967 | student/ultrasonic_anemometer | 5.43 | 127.0
2025-08-05T15:08:24.544860 | student/ultrasonic_anemometer | 5.42 | 127.0
2025-08-05T15:08:25.548267 | student/ultrasonic_anemometer | 5.51 | 127.0
2025-08-05T15:08:26.555499 | student/ultrasonic_anemometer | 5.5 | 127.0
2025-08-05T15:08:27.555338 | student/ultrasonic_anemometer | 5.52 | 127.0
2025-08-05T15:08:28.584310 | student/ultrasonic_anemometer | 5.47 | 127.0
2025-08-05T15:08:29.560540 | student/ultrasonic_anemometer | 5.45 | 126.0
2025-08-05T15:08:30.605926 | student/ultrasonic_anemometer | 5.41 | 127.0
2025-08-05T15:08:31.571754 | student/ultrasonic_anemometer | 5.38 | 127.0
2025-08-05T15:08:32.569605 | student/ultrasonic_anemometer | 5.38 | 127.0
2025-08-05T15:08:33.572508 | student/ultrasonic_anemometer | 5.39 | 127.0
2025-08-05T15:08:34.576635 | student/ultrasonic_anemometer | 5.39 | 127.0
2025-08-05T15:08:35.578340 | student/ultrasonic_anemometer | 5.34 | 127.0
2025-08-05T15:08:36.582919 | student/ultrasonic_anemometer | 5.29 | 126.0
2025-08-05T15:08:37.590792 | student/ultrasonic_anemometer | 5.27 | 127.0
2025-08-05T15:08:38.587421 | student/ultrasonic_anemometer | 5.31 | 127.0
2025-08-05T15:08:39.590636 | student/ultrasonic_anemometer | 5.37 | 127.0
2025-08-05T15:08:40.593125 | student/ultrasonic_anemometer | 5.46 | 127.0
2025-08-05T15:08:41.596597 | student/ultrasonic_anemometer | 5.45 | 127.0
2025-08-05T15:08:42.644411 | student/ultrasonic_anemometer | 5.42 | 127.0
2025-08-05T15:08:43.602490 | student/ultrasonic_anemometer | 5.42 | 126.0
2025-08-05T15:08:44.606381 | student/ultrasonic_anemometer | 5.4 | 126.0
2025-08-05T15:08:45.608591 | student/ultrasonic_anemometer | 5.36 | 125.0
2025-08-05T15:08:46.621764 | student/ultrasonic_anemometer | 5.41 | 126.0
2025-08-05T15:08:47.615998 | student/ultrasonic_anemometer | 5.4 | 125.0
2025-08-05T15:08:48.619613 | student/ultrasonic_anemometer | 5.4 | 126.0
2025-08-05T15:08:49.621772 | student/ultrasonic_anemometer | 5.42 | 126.0
2025-08-05T15:08:50.630488 | student/ultrasonic_anemometer | 5.35 | 126.0
2025-08-05T15:08:51.628371 | student/ultrasonic_anemometer | 5.36 | 126.0
2025-08-05T15:08:52.631207 | student/ultrasonic_anemometer | 5.39 | 127.0
2025-08-05T15:08:53.634158 | student/ultrasonic_anemometer | 5.35 | 127.0
2025-08-05T15:08:54.637040 | student/ultrasonic_anemometer | 5.36 | 127.0
2025-08-05T15:08:55.640112 | student/ultrasonic_anemometer | 5.44 | 128.0
2025-08-05T15:08:56.646258 | student/ultrasonic_anemometer | 5.42 | 128.0
2025-08-05T15:08:57.645799 | student/ultrasonic_anemometer | 5.4 | 128.0
2025-08-05T15:08:58.649128 | student/ultrasonic_anemometer | 5.46 | 128.0
2025-08-05T15:08:59.654860 | student/ultrasonic_anemometer | 5.46 | 128.0
2025-08-05T15:09:00.655539 | student/ultrasonic_anemometer | 5.41 | 127.0
2025-08-05T15:09:01.762784 | student/ultrasonic_anemometer | 5.37 | 128.0
2025-08-05T15:09:02.661400 | student/ultrasonic_anemometer | 5.28 | 128.0
2025-08-05T15:09:03.664324 | student/ultrasonic_anemometer | 5.27 | 128.0
2025-08-05T15:09:04.667983 | student/ultrasonic_anemometer | 5.21 | 128.0
2025-08-05T15:09:05.673141 | student/ultrasonic_anemometer | 5.17 | 127.0
2025-08-05T15:09:06.674169 | student/ultrasonic_anemometer | 5.18 | 126.0
2025-08-05T15:09:07.677027 | student/ultrasonic_anemometer | 5.25 | 126.0
2025-08-05T15:09:08.679238 | student/ultrasonic_anemometer | 5.19 | 124.0
2025-08-05T15:09:09.682429 | student/ultrasonic_anemometer | 5.19 | 124.0
2025-08-05T15:09:10.685374 | student/ultrasonic_anemometer | 5.26 | 123.0
2025-08-05T15:09:11.695530 | student/ultrasonic_anemometer | 5.42 | 123.0
2025-08-05T15:09:12.691995 | student/ultrasonic_anemometer | 5.53 | 121.0
2025-08-05T15:09:13.694426 | student/ultrasonic_anemometer | 5.6 | 121.0
2025-08-05T15:09:14.698119 | student/ultrasonic_anemometer | 5.72 | 122.0
2025-08-05T15:09:15.710940 | student/ultrasonic_anemometer | 5.82 | 123.0
2025-08-05T15:09:16.713632 | student/ultrasonic_anemometer | 5.83 | 122.0
2025-08-05T15:09:17.706515 | student/ultrasonic_anemometer | 5.83 | 122.0
2025-08-05T15:09:18.709340 | student/ultrasonic_anemometer | 5.85 | 123.0
2025-08-05T15:09:19.712519 | student/ultrasonic_anemometer | 5.91 | 123.0
2025-08-05T15:09:20.719621 | student/ultrasonic_anemometer | 5.92 | 123.0
2025-08-05T15:09:21.719380 | student/ultrasonic_anemometer | 5.86 | 123.0
2025-08-05T15:09:22.722205 | student/ultrasonic_anemometer | 5.84 | 124.0
2025-08-05T15:09:23.724433 | student/ultrasonic_anemometer | 5.84 | 123.0
2025-08-05T15:09:24.727902 | student/ultrasonic_anemometer | 5.8 | 122.0
2025-08-05T15:09:25.731781 | student/ultrasonic_anemometer | 5.73 | 122.0
2025-08-05T15:09:26.735388 | student/ultrasonic_anemometer | 5.74 | 122.0
2025-08-05T15:09:27.770969 | student/ultrasonic_anemometer | 5.75 | 122.0
2025-08-05T15:09:28.746362 | student/ultrasonic_anemometer | 5.75 | 122.0
2025-08-05T15:09:29.743004 | student/ultrasonic_anemometer | 5.72 | 122.0
2025-08-05T15:09:30.746024 | student/ultrasonic_anemometer | 5.71 | 122.0
2025-08-05T15:09:31.749307 | student/ultrasonic_anemometer | 5.73 | 122.0
2025-08-05T15:09:32.751800 | student/ultrasonic_anemometer | 5.77 | 122.0
2025-08-05T15:09:33.755683 | student/ultrasonic_anemometer | 5.74 | 123.0
2025-08-05T15:09:34.758362 | student/ultrasonic_anemometer | 5.79 | 123.0
2025-08-05T15:09:35.763975 | student/ultrasonic_anemometer | 5.81 | 123.0
2025-08-05T15:09:36.764766 | student/ultrasonic_anemometer | 5.79 | 123.0
2025-08-05T15:09:37.767159 | student/ultrasonic_anemometer | 5.79 | 123.0
2025-08-05T15:09:38.769890 | student/ultrasonic_anemometer | 5.8 | 123.0
2025-08-05T15:09:39.773281 | student/ultrasonic_anemometer | 5.78 | 122.0
2025-08-05T15:09:40.775903 | student/ultrasonic_anemometer | 5.8 | 122.0
2025-08-05T15:09:41.781415 | student/ultrasonic_anemometer | 5.85 | 123.0
2025-08-05T15:09:42.782151 | student/ultrasonic_anemometer | 5.82 | 122.0
2025-08-05T15:09:43.785355 | student/ultrasonic_anemometer | 5.87 | 122.0
2025-08-05T15:09:44.791372 | student/ultrasonic_anemometer | 5.84 | 122.0
2025-08-05T15:09:45.791462 | student/ultrasonic_anemometer | 5.87 | 122.0
2025-08-05T15:09:46.793958 | student/ultrasonic_anemometer | 5.9 | 123.0
2025-08-05T15:09:47.797334 | student/ultrasonic_anemometer | 5.91 | 122.0
2025-08-05T15:09:48.799694 | student/ultrasonic_anemometer | 5.97 | 123.0
2025-08-05T15:09:49.808683 | student/ultrasonic_anemometer | 6.03 | 123.0
2025-08-05T15:09:50.806249 | student/ultrasonic_anemometer | 6.03 | 124.0
2025-08-05T15:09:51.809918 | student/ultrasonic_anemometer | 6.03 | 124.0
2025-08-05T15:09:52.813193 | student/ultrasonic_anemometer | 6.11 | 125.0
2025-08-05T15:09:53.817152 | student/ultrasonic_anemometer | 6.14 | 126.0
2025-08-05T15:09:54.819186 | student/ultrasonic_anemometer | 6.18 | 126.0
2025-08-05T15:09:55.822167 | student/ultrasonic_anemometer | 6.2 | 126.0
2025-08-05T15:09:56.824763 | student/ultrasonic_anemometer | 6.2 | 126.0
2025-08-05T15:09:57.827233 | student/ultrasonic_anemometer | 6.18 | 126.0

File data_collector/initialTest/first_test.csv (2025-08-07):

timestamp | topic | wind_speed | wind_direction
2025-08-05T15:02:16.448921 | student/ultrasonic_anemometer | 5.51 | 128.0
2025-08-05T15:02:17.451474 | student/ultrasonic_anemometer | 5.53 | 128.0
2025-08-05T15:02:18.454404 | student/ultrasonic_anemometer | 5.48 | 127.0
2025-08-05T15:02:19.457607 | student/ultrasonic_anemometer | 5.48 | 127.0
2025-08-05T15:02:20.541367 | student/ultrasonic_anemometer | 5.44 | 127.0
2025-08-05T15:02:21.463140 | student/ultrasonic_anemometer | 5.43 | 126.0
2025-08-05T15:02:22.465804 | student/ultrasonic_anemometer | 5.45 | 126.0
2025-08-05T15:02:23.469744 | student/ultrasonic_anemometer | 5.45 | 125.0
2025-08-05T15:02:24.472567 | student/ultrasonic_anemometer | 5.45 | 125.0
2025-08-05T15:02:25.477003 | student/ultrasonic_anemometer | 5.41 | 125.0
2025-08-05T15:02:26.477700 | student/ultrasonic_anemometer | 5.36 | 125.0
2025-08-05T15:02:27.481212 | student/ultrasonic_anemometer | 5.32 | 126.0
2025-08-05T15:02:28.483585 | student/ultrasonic_anemometer | 5.34 | 126.0
2025-08-05T15:02:29.487859 | student/ultrasonic_anemometer | 5.35 | 126.0
2025-08-05T15:02:30.489486 | student/ultrasonic_anemometer | 5.33 | 126.0
2025-08-05T15:02:31.492621 | student/ultrasonic_anemometer | 5.28 | 127.0
2025-08-05T15:02:32.495486 | student/ultrasonic_anemometer | 5.15 | 128.0
2025-08-05T15:02:33.499295 | student/ultrasonic_anemometer | 5.02 | 128.0
2025-08-05T15:02:34.501375 | student/ultrasonic_anemometer | 4.94 | 128.0
2025-08-05T15:02:35.504386 | student/ultrasonic_anemometer | 4.93 | 129.0
2025-08-05T15:02:36.507299 | student/ultrasonic_anemometer | 4.86 | 129.0
2025-08-05T15:02:37.511233 | student/ultrasonic_anemometer | 4.83 | 128.0
2025-08-05T15:02:38.513106 | student/ultrasonic_anemometer | 4.82 | 128.0
2025-08-05T15:02:39.517386 | student/ultrasonic_anemometer | 4.82 | 129.0
2025-08-05T15:02:40.518693 | student/ultrasonic_anemometer | 4.82 | 129.0
2025-08-05T15:02:41.522050 | student/ultrasonic_anemometer | 4.88 | 129.0
2025-08-05T15:02:42.524565 | student/ultrasonic_anemometer | 4.92 | 128.0
2025-08-05T15:02:43.529906 | student/ultrasonic_anemometer | 4.97 | 128.0
2025-08-05T15:02:44.531298 | student/ultrasonic_anemometer | 5.0 | 129.0
2025-08-05T15:02:45.534632 | student/ultrasonic_anemometer | 5.02 | 129.0
2025-08-05T15:02:46.536704 | student/ultrasonic_anemometer | 5.1 | 129.0
2025-08-05T15:02:47.542304 | student/ultrasonic_anemometer | 5.09 | 129.0
2025-08-05T15:02:48.542900 | student/ultrasonic_anemometer | 5.05 | 128.0
2025-08-05T15:02:49.548144 | student/ultrasonic_anemometer | 4.99 | 127.0
2025-08-05T15:02:50.550755 | student/ultrasonic_anemometer | 4.98 | 128.0
2025-08-05T15:02:51.551437 | student/ultrasonic_anemometer | 4.99 | 128.0
2025-08-05T15:02:52.554302 | student/ultrasonic_anemometer | 5.05 | 128.0
2025-08-05T15:02:53.639152 | student/ultrasonic_anemometer | 5.11 | 128.0
2025-08-05T15:02:54.561801 | student/ultrasonic_anemometer | 5.16 | 128.0
2025-08-05T15:02:55.563019 | student/ultrasonic_anemometer | 5.23 | 128.0
2025-08-05T15:02:56.569971 | student/ultrasonic_anemometer | 5.2 | 127.0
2025-08-05T15:02:57.569485 | student/ultrasonic_anemometer | 5.27 | 126.0
2025-08-05T15:02:58.571505 | student/ultrasonic_anemometer | 5.35 | 127.0
2025-08-05T15:02:59.575955 | student/ultrasonic_anemometer | 5.44 | 128.0
2025-08-05T15:03:00.582122 | student/ultrasonic_anemometer | 5.44 | 128.0
2025-08-05T15:03:01.581414 | student/ultrasonic_anemometer | 5.46 | 128.0
2025-08-05T15:03:02.583388 | student/ultrasonic_anemometer | 5.4 | 127.0
2025-08-05T15:03:03.586466 | student/ultrasonic_anemometer | 5.43 | 127.0
2025-08-05T15:03:04.592108 | student/ultrasonic_anemometer | 5.43 | 127.0
2025-08-05T15:03:05.618730 | student/ultrasonic_anemometer | 5.42 | 127.0
2025-08-05T15:03:06.595566 | student/ultrasonic_anemometer | 5.45 | 128.0
2025-08-05T15:03:07.598671 | student/ultrasonic_anemometer | 5.44 | 128.0
2025-08-05T15:03:08.604001 | student/ultrasonic_anemometer | 5.36 | 128.0
2025-08-05T15:03:09.605111 | student/ultrasonic_anemometer | 5.35 | 128.0
2025-08-05T15:03:10.607387 | student/ultrasonic_anemometer | 5.41 | 127.0
2025-08-05T15:03:11.609953 | student/ultrasonic_anemometer | 5.36 | 128.0
2025-08-05T15:03:12.613284 | student/ultrasonic_anemometer | 5.4 | 128.0
2025-08-05T15:03:13.662038 | student/ultrasonic_anemometer | 5.35 | 128.0
2025-08-05T15:03:14.619513 | student/ultrasonic_anemometer | 5.34 | 127.0
2025-08-05T15:03:15.621652 | student/ultrasonic_anemometer | 5.35 | 126.0
2025-08-05T15:03:16.626983 | student/ultrasonic_anemometer | 5.35 | 126.0
2025-08-05T15:03:17.627528 | student/ultrasonic_anemometer | 5.37 | 126.0
2025-08-05T15:03:18.632301 | student/ultrasonic_anemometer | 5.42 | 126.0
2025-08-05T15:03:19.633329 | student/ultrasonic_anemometer | 5.39 | 126.0
2025-08-05T15:03:20.636333 | student/ultrasonic_anemometer | 5.4 | 126.0
2025-08-05T15:03:21.642965 | student/ultrasonic_anemometer | 5.41 | 126.0
2025-08-05T15:03:22.644713 | student/ultrasonic_anemometer | 5.41 | 125.0
2025-08-05T15:03:23.650893 | student/ultrasonic_anemometer | 5.44 | 126.0
2025-08-05T15:03:24.649775 | student/ultrasonic_anemometer | 5.43 | 127.0
2025-08-05T15:03:25.653150 | student/ultrasonic_anemometer | 5.45 | 127.0
2025-08-05T15:03:26.655368 | student/ultrasonic_anemometer | 5.38 | 127.0
2025-08-05T15:03:27.658180 | student/ultrasonic_anemometer | 5.33 | 127.0
2025-08-05T15:03:28.663431 | student/ultrasonic_anemometer | 5.36 | 127.0
2025-08-05T15:03:29.664560 | student/ultrasonic_anemometer | 5.43 | 127.0
2025-08-05T15:03:30.667249 | student/ultrasonic_anemometer | 5.44 | 127.0
2025-08-05T15:03:31.676985 | student/ultrasonic_anemometer | 5.45 | 127.0
2025-08-05T15:03:32.674035 | student/ultrasonic_anemometer | 5.44 | 127.0
2025-08-05T15:03:33.677157 | student/ultrasonic_anemometer | 5.39 | 126.0
2025-08-05T15:03:34.678839 | student/ultrasonic_anemometer | 5.38 | 127.0
2025-08-05T15:03:35.682054 | student/ultrasonic_anemometer | 5.31 | 126.0
2025-08-05T15:03:36.685437 | student/ultrasonic_anemometer | 5.37 | 127.0
2025-08-05T15:03:37.687848 | student/ultrasonic_anemometer | 5.42 | 127.0
2025-08-05T15:03:38.698235 | student/ultrasonic_anemometer | 5.43 | 128.0
2025-08-05T15:03:39.694639 | student/ultrasonic_anemometer | 5.39 | 127.0
2025-08-05T15:03:40.698411 | student/ultrasonic_anemometer | 5.35 | 127.0
2025-08-05T15:03:41.699233 | student/ultrasonic_anemometer | 5.37 | 127.0
2025-08-05T15:03:42.702012 | student/ultrasonic_anemometer | 5.38 | 127.0
2025-08-05T15:03:43.707458 | student/ultrasonic_anemometer | 5.4 | 128.0
2025-08-05T15:03:44.707844 | student/ultrasonic_anemometer | 5.38 | 127.0
2025-08-05T15:03:45.757419 | student/ultrasonic_anemometer | 5.38 | 127.0
2025-08-05T15:03:46.714253 | student/ultrasonic_anemometer | 5.35 | 126.0
2025-08-05T15:03:47.717515 | student/ultrasonic_anemometer | 5.37 | 126.0
2025-08-05T15:03:48.719791 | student/ultrasonic_anemometer | 5.31 | 126.0
2025-08-05T15:03:49.723187 | student/ultrasonic_anemometer | 5.31 | 126.0
2025-08-05T15:03:50.725441 | student/ultrasonic_anemometer | 5.29 | 125.0
2025-08-05T15:03:51.729767 | student/ultrasonic_anemometer | 5.25 | 125.0
2025-08-05T15:03:52.730899 | student/ultrasonic_anemometer | 5.24 | 125.0
2025-08-05T15:03:53.734874 | student/ultrasonic_anemometer | 5.27 | 125.0
2025-08-05T15:03:54.737418 | student/ultrasonic_anemometer | 5.3 | 126.0
2025-08-05T15:03:55.742298 | student/ultrasonic_anemometer | 5.32 | 126.0

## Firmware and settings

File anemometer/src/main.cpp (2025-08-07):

// Sonic Anemometer

#include <math.h>
#include <Arduino.h>

#include "sevSeg.hpp"

#define ADC_DELAY_US 100
#define MOVING_AVERAGE_SIZE 50
#define DISPLAY_UPDATE_RATE 1000

#define WEST_PIN A0
#define EAST_PIN A1

typedef struct{
  float windSpeed; // Wind speed in m/s
  int windDirection; // Wind direction in degrees
} WindData_t;

typedef struct{
  int W;
  int E;
} Wind_t;

// Calibration values for the sensors in still air
                      // W  , E
const Wind_t calm =   {547, 581}; // Calibration values for still air
const Wind_t north =  {850, 226}; // Calibration values for north wind
const Wind_t east =   {720, 712}; // Calibration values for east wind

const float windspeed = 10;   //Wind speed during calibration

// Define the pins for the 7-segment display
sevSeg myDisplay;
uint8_t digitPins[4] = {3, 2, 13, 12}; // Pins for the digits
uint8_t segmentPins[8] = {4, 5, 6, 7, 8, 9, 10, 11}; // Pins for the segments

WindData_t windCalculations(int reading, bool sensorSelect);
 
void setup()
{
  Serial.begin(9600);
  pinMode(WEST_PIN, INPUT);
  pinMode(EAST_PIN, INPUT);
  
  Serial.println("Sonic Anemometer");

  delay(1000);

  myDisplay.begin(digitPins, segmentPins); // Initialize the 7-segment display

  // Check if calibration values are zero
  if(north.W == calm.W || north.E == calm.E || east.W == calm.W || east.W == calm.E) {
    Serial.println("Error: Calibration values cannot be zero, check calibration values.");
    return; // Exit if calibration values are zero
  }
}
void loop()
{
  static unsigned long lastReading = millis();
  static unsigned long lastUpdate = millis();
  static int reading = 0; // int to hold the voltages from the sensors
  static bool sensorSelect = false; // Switch to alternate between east and west sensor readings
  // false = east sensor, true = west sensor

  static WindData_t windData; // Structure to hold wind data

  // Check which sensor to read based on the switch
  // This is because analog read takes 112us, so this reduces the time between readings
  if(millis() - lastReading >= ADC_DELAY_US){
    lastReading = millis(); // Update the last reading time
    reading = (sensorSelect) ? analogRead(WEST_PIN) : analogRead(EAST_PIN); // Measure sensor voltage
    windData = windCalculations(reading, sensorSelect); // Perform wind calculations
    sensorSelect = !sensorSelect; // Switch to the other sensor for the next reading
    Serial.println("{" + String(windData.windSpeed) + ", " + String(windData.windDirection) + "}"); // Print the wind data
  } 

  // Update the value at the Display
  if(millis() - lastUpdate >= DISPLAY_UPDATE_RATE){
    myDisplay.setNumber(round(windData.windSpeed));
    Serial.println("{speed:" + String(windData.windSpeed) + ",direction:" + String(windData.windDirection) + "}"); // Print the wind data
    lastUpdate = millis(); // Update the last update time
  }

  myDisplay.refreshDisplayNumber(); // Update the display with the new number
}

WindData_t windCalculations(int reading, bool sensorSelect)
{
  static int eastAvgArray[MOVING_AVERAGE_SIZE] = {0}; // Array to store east sensor readings
  static int westAvgArray[MOVING_AVERAGE_SIZE] = {0}; // Array to store west sensor readings

  static int eastAvgIndex = 0; // Index for east sensor readings
  static int westAvgIndex = 0; // Index for west sensor readings

  static float eastSum = 0; // Sum values for east and west sensors
  static float westSum = 0; // Sum values for east and west sensors

  WindData_t windData; // Structure to hold wind data

  // Rolling Average Calculation
  if(sensorSelect){
    // West Sensor Update
    westSum += reading;                                       // Add current west sensor reading to sum
    westSum -= westAvgArray[westAvgIndex];                    // Subtract the oldest west sensor reading from sum
    westAvgArray[westAvgIndex] = reading;                     // Store the current west sensor reading
    westAvgIndex = (westAvgIndex + 1) % MOVING_AVERAGE_SIZE;  // Update index for west sensor
  }
  else{
    // East Sensor Update
    eastSum += reading;                                       // Add current east sensor reading to sum
    eastSum -= eastAvgArray[eastAvgIndex];                    // Subtract the oldest east sensor reading from sum
    eastAvgArray[eastAvgIndex] = reading;                     // Store the current east sensor reading
    eastAvgIndex = (eastAvgIndex + 1) % MOVING_AVERAGE_SIZE;  // Update index for east sensor
  }

  // Serial.print("West sensor average: ");
  // Serial.println(westSum / MOVING_AVERAGE_SIZE);
  // Serial.print("East sensor average: ");
  // Serial.println(eastSum / MOVING_AVERAGE_SIZE);

  // Calculate West and East Transducer vectors
  float NW_WS_W = windspeed * (((westSum/MOVING_AVERAGE_SIZE) - calm.W) / (north.W - calm.W)); // North wind vector at West Transducer
  float NW_WS_E = windspeed * (((eastSum/MOVING_AVERAGE_SIZE) - calm.E) / (north.E - calm.E)); // North wind vector at East Transducer
  float EW_WS_W = windspeed * (((westSum/MOVING_AVERAGE_SIZE) - calm.W) / (east.W - calm.W)); // East wind vector at West Transducer
  float EW_WS_E = windspeed * (((eastSum/MOVING_AVERAGE_SIZE) - calm.E) / (east.E - calm.E)); // East wind vector at East Transducer

  float northWind = NW_WS_W + NW_WS_E; // Calculate the north wind vector
  float eastWind = EW_WS_W + EW_WS_E; // Calculate the east wind vector

  windData.windSpeed = sqrt((northWind * northWind) + (eastWind * eastWind)) / 2; // Calculate the wind speed

  windData.windDirection = round((180/PI) * (atan2(northWind, eastWind)));
  if(windData.windDirection < 0)
    windData.windDirection += 360; // Normalize the wind direction to be between 0 and 360 degrees

  // Serial.print("Wind speed ");
  // Serial.print(windData.windSpeed);
  // Serial.println(" m/s");
  // Serial.print("Wind direction " );
  // Serial.print(windData.windDirection);
  // Serial.println(" degrees");

  return windData; // Return the wind data structure
}

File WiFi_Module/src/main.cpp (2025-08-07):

#include <Arduino.h>
#include <WiFi.h>
#include <PubSubClient.h>

#include "./arduino_secrets.h"

#define INTERVAL 10000 // 10 seconds

// WiFi credentials
const char *wifi_ssid = SECRET_SSID;
const char *wifi_password = SECRET_PASS;

// MQTT credentials
const char *mqtt_username = SECRET_MQTTUSER;
const char *mqtt_password = SECRET_MQTTPASS;
const char *mqtt_server = "mqtt.cetools.org";
const char *mqtt_topic = "student/ultrasonic_anemometer/data";
const int mqtt_port = 1884;



// Global Objects
WiFiClient wifiClient;
PubSubClient mqttClient(wifiClient);

// Function Declarations
void startWifi(void);
void checkWifi(void);
void checkMQTT(void);
void sendMQTT(char *msg);

void setup() {
  // Set software serial baud to 115200;
  Serial.begin(9600);
  delay(1000); // Wait for Serial to initialize

  Serial.println("ESP32 MQTT");
  delay(1000);

  // Start WiFi connection
  Serial.println("Connecting to WiFi...");
  startWifi();

  // Initialize MQTT client
  mqttClient.setServer(mqtt_server, mqtt_port);
}

void loop() {
  char mqtt_msg[100];
  
  if(Serial.available()) {
    
    String input = Serial.readStringUntil('\n');
    // Prepare MQTT message
    sprintf(mqtt_msg, input.c_str());
    sendMQTT(mqtt_msg);
  }

  // Ensure WiFi and MQTT connections are maintained
  checkWifi();
  checkMQTT();
}

void startWifi(void)
{
  WiFi.mode(WIFI_STA);
  WiFi.begin(wifi_ssid, wifi_password);
  Serial.print("Connecting to WiFi ..");
  while (WiFi.status() != WL_CONNECTED) {
    Serial.print('.');
    delay(1000);
  }
  Serial.println(WiFi.localIP());
}

void checkWifi(void)
{
    // Reconnect to WiFi if disconnected
  static unsigned long previousMillis = 0;
  unsigned long currentMillis = millis();
  // if WiFi is down, try reconnecting
  if ((WiFi.status() != WL_CONNECTED) && (currentMillis - previousMillis >= INTERVAL)) {
    Serial.print(millis());
    Serial.println("Reconnecting to WiFi...");
    WiFi.disconnect();
    WiFi.reconnect();
    previousMillis = currentMillis;
  }
}

void checkMQTT(void)
{
  if(WiFi.status() != WL_CONNECTED) {
    checkWifi();
  }

  while(!mqttClient.connected()) {
    Serial.print("Attempting MQTT connection...");
    // Attempt to connect
    if(mqttClient.connect("ESP32Client", mqtt_username, mqtt_password)) {
      Serial.println("connected");
      // Subscribe to a topic if needed
      // mqttClient.subscribe("your/topic");
    } else {
      Serial.print("failed, rc=");
      Serial.print(mqttClient.state());
      Serial.println(" try again in 5 seconds");
      delay(5000);
    }
  }
}

void sendMQTT(char *msg)
{
  char mqttTopic[35];
  sprintf(mqttTopic, "student/ultrasonic_anemometer");
  
  Serial.println("SENDING MSG...");
  Serial.print("Topic: ");
  Serial.println(mqttTopic);
  Serial.print("Message: ");
  Serial.println(msg);

  if (mqttClient.publish(mqttTopic, msg))
  {
    Serial.println("Message published");
  }
  else
  {
    Serial.println("Failed to publish message");
  }

  delay(1000); // Wait for a second before next operation
}

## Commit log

2025-07-07 chore: storing everything I currently have
    [Spur Gear 36 Teeth - Spur Gear.stl, Upper Rack.stl, building.dxf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]
2025-07-08 chore: having issues with sample rate
    [baseBox.dxf]
2025-07-12 chore: added new models for the exhibit, and made some code adjustments to read from ADC using the ADC HAL Library
    [Upper Rack_v2.stl, fanBox.dxf, pinionGearMount.stl]
2025-07-17 chore: cad model updates:
    [accelerator box - Part 1.stl, circuitBox - Part 1.stl, fanBox.dxf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]
2025-07-28 feat: cad and a rudimentary codebase written for the 2D anemometer.
    [arduinoBox.stl, batteryBox.stl, circuitBox - Part 1.stl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]
2025-07-30 chore: cleaned up the algorithm, and code. One bug remains, the North wind seems to be way higher than I would expect.
    [main.cpp]
2025-08-01 feat: closing work on this branch. The Arduino code is ready to go, and includes the serial prints to the wifi module
2025-08-07 feat: removed some key secrets
    [Spur Gear 36 Teeth - Spur Gear.stl, Upper Rack.stl, Upper Rack_v2.stl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]
2025-08-08 feat: took readings in various settings
    [bigFan_open_building_treeStrip.csv, bigFan_open_treeStrip.csv, bigFan_semiClosed.csv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]
2025-08-17 chore: moving around the data
    [ATL_half_building_park.csv, ATL_open_building_park.csv, GL_half_building_park.csv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]
2025-08-19 chore: minor issue of filtering by trees, not parks
